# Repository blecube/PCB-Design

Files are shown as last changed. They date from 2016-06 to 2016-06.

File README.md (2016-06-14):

##BLE CUBE - PCB Design
This is the repository for all PCB Design files. Included in this repository is:

####BLE Card
This card features three 8-bit shift registers. The parallell outputs of these can be found alongside the edges of the card.
BLE Card supports two types of accelerometers. One internal [(LIS2DH12)](http://www.st.com/content/ccc/resource/technical/document/datasheet/12/c0/5c/36/b9/58/46/f2/DM00091513.pdf/files/DM00091513.pdf/jcr:content/translations/en.DM0009151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) that features its own traces and a header pin for an external accelerometer.

For more information, see pin assignements and pin map.

Also available is Components and Bill of Materials, BOM. Some of the used components are not included. See bottom of the BOM for details.
Further information on the circuits reference design can be found at Nordic Semiconductors infocenter

**Disclaimer!** This PCB as it is now is designed for use with LEDs that runs on 3V. Resistors are 390 ohm, but should be lower if 3v LEDs are to utilized. This part of the project was significantly modified in our case. This must be kept in mind if you want to replicate the project. In our case, the shiftregisters was modified to run on 4.2V in order to function with the LEDs.

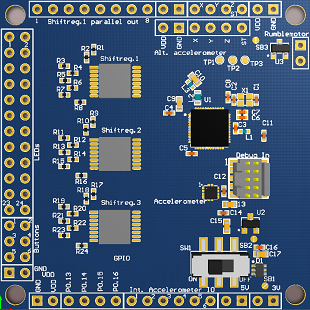
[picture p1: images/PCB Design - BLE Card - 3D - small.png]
BLE Card


####Adapter Card
* Designed for using [Adafruits chargecircuit](https://www.adafruit.com/product/259).
* Can be modified to send battery status lines to either P0.30 and P0.29, or P0.13 and P0.14. These can be used to program the cube to indicate "charging" or "charge complete".

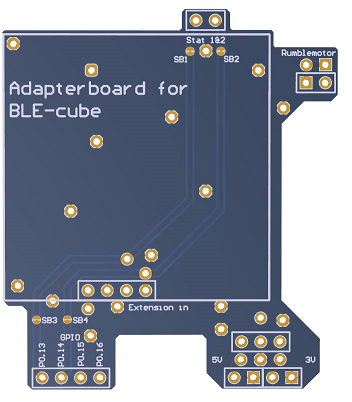
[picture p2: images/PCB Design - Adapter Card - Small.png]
BLE Card


####Schematic
The file called Schematics - BLE Card shows all connections, nets and components on the BLE Card.

####Recommended battery
If the adafruit charger is used, we recommend this battery to be used alongside our adapter card: [https://www.adafruit.com/products/328](https://www.adafruit.com/products/328)

> Created by Rasmus Espset

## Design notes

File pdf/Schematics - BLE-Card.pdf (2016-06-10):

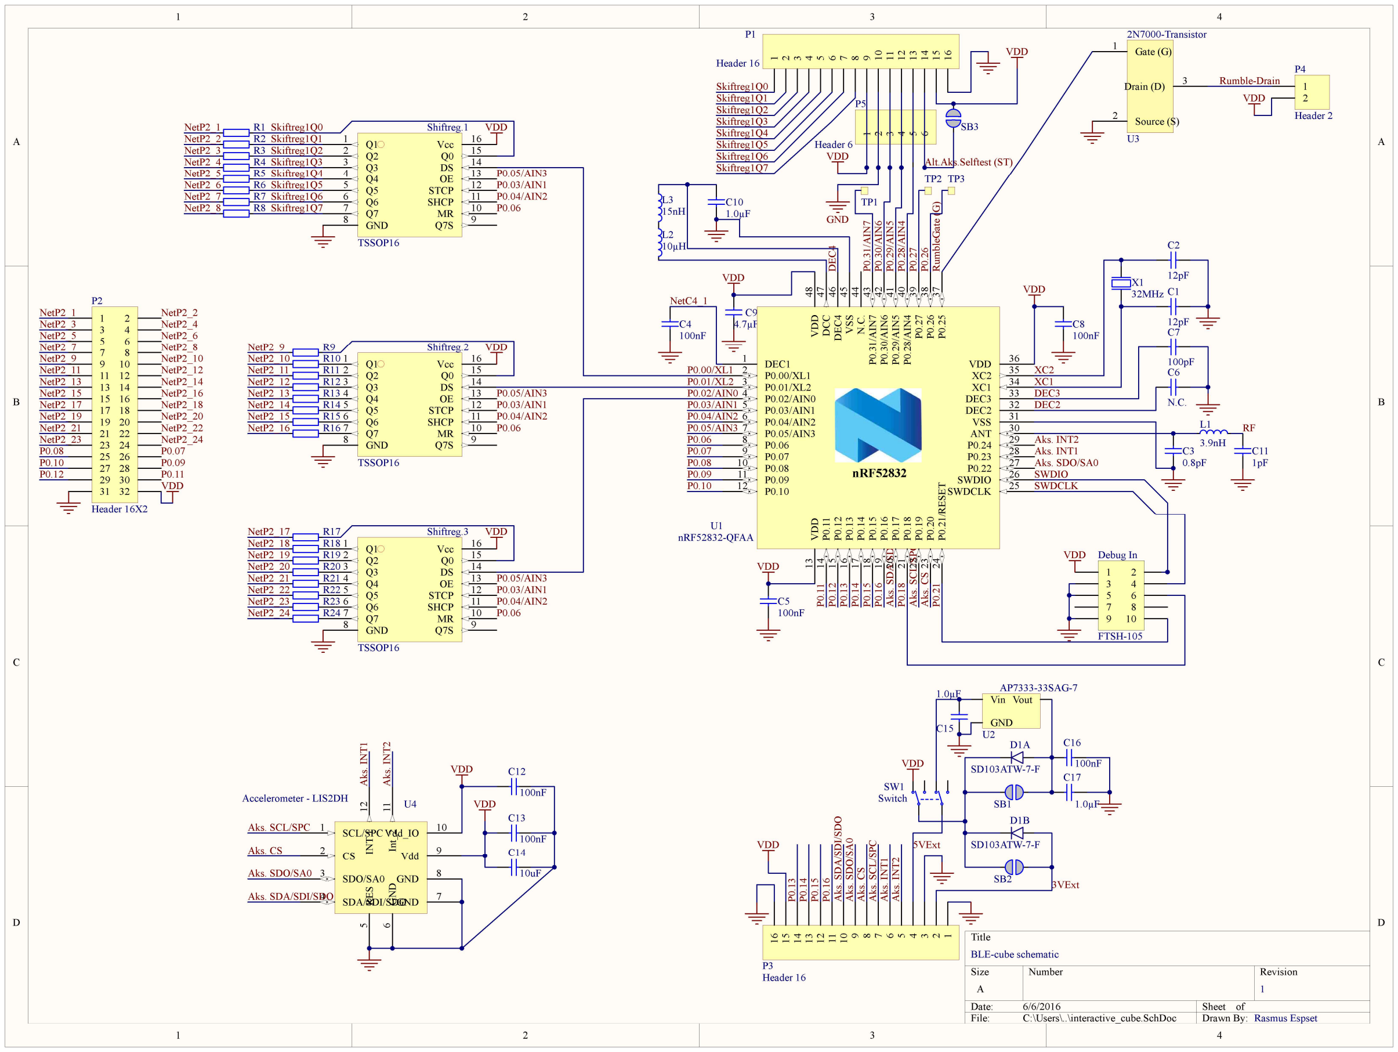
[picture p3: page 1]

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
Title
Size | Number | Revision
A
Date: | 6/6/2016 | Sheet of
File: | C:\Users\..\interactive_cube.SchDoc Drawn By:

X1
32MHz C1
12pF

C2
12pF

C7
100pF

C9
C4 4.7µF
100nF

C5
100nF

XC1

XC2

VDD

P0.07
P0.08
P0.10 | P⁰.11 P⁰.12 P⁰.13 P⁰.14 | Aks. SDA/SDI/SDO P⁰.18 Aks. SCL/SPC Aks. CS P⁰.21

Aks. SDO/SA0

Aks. INT1

Aks. INT2 RumbleGate ⁽G⁾
NetC4_1 | P⁰.29/AIN⁵ P⁰.28/AIN⁴

SWDCLK

SWDIO

L2
10µH

C10
1.0µF

L3
15nH

P0.06

RF
C3
0.8pF

C8
100nF

L1
3.9nH

C6
N.C.

P0.00/XL1

P0.01/XL2 | P⁰.27 P⁰.26

VDD

DEC1 1

P0.10 12 VDD 13

VSS 31
ANT 30

DEC2 32 DEC3 33 XC1 34 XC2 35 VDD 36 P⁰.25 37 P⁰.26 38

P0.00/XL1 2
P0.01/XL2 3
P0.02/AIN0 4
P0.03/AIN1 5
P0.04/AIN2 6
P0.05/AIN3 7
P0.06 8
P0.07 9
P0.08 10
P0.09 11 | P⁰.11 14 P⁰.12 15 P⁰.13 16 P⁰.14 17 | P⁰.27 39 P⁰.28/AIN⁴ ⁴⁰ P⁰.29/AIN⁵ ⁴¹ P⁰.30/AIN⁶ ⁴² P⁰.31/AIN⁷ ⁴³ N.C. 44 DEC⁴ ⁴⁶ VSS ⁴⁵ VDD ⁴⁸ DCC ⁴⁷

SWDCLK 25 SWDIO 26 P0.22 27 P0.23 28 P0.24 29 P⁰.15 18 P⁰.16 19 P⁰.17 20 P⁰.18 21 P⁰.20 23 P⁰.21/RESET 24 P⁰.19 22

### nRF52832

U1
nRF52832-QFAA

VDD

P0.02/AIN0 | DEC3
P0.03/AIN1
P0.04/AIN2
P0.05/AIN3 | P⁰.15 P⁰.16
P0.09 | DEC⁴ | P⁰.31/AIN⁷ P⁰.30/AIN⁶

DEC2

C11
1pF

1 2
3 4
5
7 8
9 10

6

Debug In

FTSH-105

Q2 2
Q3 3
Q4 4
Q5 5
Q6 6
Q7 7
GND 8 | Q7S 9 MR 10 SHCP 11 STCP 12 OE 13 DS 14 Q0 15 Vcc 16 Q1 1

Shiftreg.2

TSSOP16

Q2 2
Q3 3
Q4 4
Q5 5
Q6 6
Q7 7
GND 8 | Q7S 9 MR 10 SHCP 11 STCP 12 OE 13 DS 14 Q0 15 Vcc 16 Q1 1

Shiftreg.3

TSSOP16

SCL/SPC 1
CS 2
SDO/SA0 3
SDA/SDI/SDO 4 RES

### 5 GND

6

GND 7

GND 8

Vdd 9

Vdd_IO 10 Int_2 11 INT ¹ ¹² U4 Accelerometer - LIS2DH

C12
100nF
C13
100nF
C14
10uF

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
Switch

VDD

Source (S) 2

Drain (D) 3

Gate (G) 1

U3

2N7000-Transistor

VDD

VDD
SB3

D1A
SD103ATW-7-F

D1B
SD103ATW-7-F

SB1

SB2

C16
100nF

5VExt
3VExt

Vin
GND

Vout
U2

AP7333-33SAG-7

VDD

VDD 1

2

3

4

5

6

P5
Header 6

TP1

TP2 TP3

VDD

Aks. SCL/SPC
Aks. CS
Aks. SDO/SA0
Aks. SDA/SDI/SDO Aks. INT¹ Aks. INT² | P⁰.13 P⁰.14 P⁰.15 P⁰.16 Aks. SDA/SDI/SDO Aks. SDO/SA⁰ Aks. CS Aks. SCL/SPC Aks. INT¹ Aks. INT²

P0.12

P0.10

P0.08

NetP2_23

NetP2_21

P0.11

P0.09

P0.07

NetP2_24

NetP2_22

NetP2_20

NetP2_18

NetP2_16

NetP2_14

NetP2_12

NetP2_10

NetP2_8

NetP2_6

NetP2_4

NetP2_2

NetP2_19

NetP2_17

NetP2_15

NetP2_13

NetP2_11

NetP2_9

NetP2_7

NetP2_5

NetP2_3

NetP2_1

Skiftreg1Q0
Skiftreg1Q1
Skiftreg1Q2
Skiftreg1Q3
Skiftreg1Q4
Skiftreg1Q5
Skiftreg1Q6
Skiftreg1Q7

NetP2_24

Skiftreg1Q0
Skiftreg1Q1
Skiftreg1Q2
Skiftreg1Q3
Skiftreg1Q4
Skiftreg1Q5
Skiftreg1Q6
Skiftreg1Q7

NetP2_1
NetP2_2
NetP2_3
NetP2_4
NetP2_5
NetP2_6
NetP2_7
NetP2_8

P0.05/AIN3

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
116151413121110
P3
Header 16

Q2 2
Q3 3
Q4 4
Q5 5
Q6 6
Q7 7
GND 8 | Q7S 9 MR 10 SHCP 11 STCP 12 OE 13 DS 14 Q0 15 Vcc 16 Q1 1

Shiftreg.1

TSSOP16

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
910111213141516

P1
Header 16

1 2
3 4
5 6
7 8
9 10
11 12
13 14
15 16
17 18
19 20
21 22
23 24
25 26
27 28
29 30
31 32

P2

Header 16X2

P0.06

P0.06

P0.06

P0.05/AIN3

P0.05/AIN3

P0.04/AIN2

P0.04/AIN2

P0.04/AIN2

P0.03/AIN1

P0.03/AIN1

P0.03/AIN1

NetP2_9
NetP2_10
NetP2_11
NetP2_12
NetP2_13
NetP2_14
NetP2_15
NetP2_16

NetP2_17
NetP2_18
NetP2_19
NetP2_20
NetP2_21
NetP2_22
NetP2_23

Alt.Aks.Selftest (ST)

1
2

P4

Header 2

Rumble-Drain

C17
1.0µF

C15

1.0µF

BLE-cube schematic

Rasmus Espset

1

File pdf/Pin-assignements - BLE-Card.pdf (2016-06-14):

## 1.1 Pin-assignements - BLE-cube circuit board (nRF52)

http://bit.ly/1XA3fwh

Name | Pin | Type / Function | Comment
DEC1 | 1 | Decoupling cap. 1 | 0V9 regulator digital supply decoupling.
P0.00 | 2 | Serial data 1 | Shiftreg.1: serial data input.
P0.01 | 3 | Serial data 2 | Shiftreg.2: serial data input.
P0.02 | 4 | Serial data 3 | Shiftreg.3: serial data input.
P0.03 | 5 | RCLK | Shiftreg.1, 2, 3: storage register clock.
P0.04 | 6 | SRCLK | Shiftreg.1, 2, 3: shift register clock.
P0.05 | 7 | OE (inv.) | Shiftreg.1, 2, 3: Output Enable.
P0.06 | 8 | SRCLK (inv.) | Shiftreg.1, 2, 3: direct overriding clear.
P0.07 | 9 | Button 2 | GPIO, used for button inputs.
P0.08 | 10 | Button 1 | GPIO, used for button inputs.
P0.09 | 11 | Button 4 | GPIO, used for button inputs.
P0.10 | 12 | Button 3 | GPIO, used for button inputs.
VDD | 13 | Power | Supply Voltage.
P0.11 | 14 | Button 6 | GPIO, used for button inputs.
P0.12 | 15 | Button 5 | GPIO, used for button inputs.
P0.13 | 16 | P0.13 | GPIO.
P0.14 | 17 | P0.14 | GPIO.
P0.15 | 18 | P0.15 | GPIO.
P0.16 | 19 | P0.16 | GPIO.

P0.17 | 20 | Accel. SDA/SDI/SDO | Internal accelerometer pin (GPIO if unused).
P0.18 | 21 | Debug pin 6: TRACECTL | Single Wire Output.
P0.19 | 22 | Accel. SCL/SPC | Internal accelerometer (GPIO if unused).
P0.20 | 23 | Accel. CS | Internal accelerometer (GPIO if unused).
P0.21/RESET | 24 | Reset | Debug pin 10.
SWDCLK | 25 | Debug pin 4 | Serial Wire Debug clock input for debug and programming.
SWDIO | 26 | Debug pin 2 | Serial Wire Debug I/O for debug and programming.
P0.22 | 27 | Accel. SDO/SA0 | Internal accelerometer pin (GPIO if unused).
P0.23 | 28 | Accel. INT1 | Internal accelerometer pin: Interrupt signal 1 (GPIO if unused).
P0.24 | 29 | Accel. INT2 | Internal accelerometer pin: Interrupt signal 2 (GPIO if unused).
ANT | 30 | RF | Single-ended radio antenna connection.
VSS | 31 | Power | Ground pin (Radio supply).
DEC2 | 32 | Decoupling cap. 2 | 1V3 regulator supply decoupling (Radio supply).
DEC3 | 33 | Decoupling cap. 3 | Power supply decoupling.
XC1 | 34 | Analog Input | Connection for 32 MHz crystal.
XC2 | 35 | Analog Input | Connection for 32 MHz crystal.
VDD | 36 | Power | Supply Voltage.
P0.25 | 37 | RumbleGate (G) | Gate on transistor U3.
P0.26 | 38 | TP3 | Testpoint 3.
P0.27 | 39 | TP2 | Testpoint 2.
P0.28 | 40 | Z-signal - (AIN4 - Analog input) | External accelerometer: Z-values.
P0.29 | 41 | Y-signal - (AIN5 - Analog input) | External accelerometer: Y-values.

P0.30 | 42 | X-signal - (AIN6 - Analog input) | External accelerometer: X-values.
P0.31 | 43 | TP1 (AIN7 - Analog input) | Testpoint 1.
N.C | 44 | | Not Connected.
VSS | 45 | Power | Ground Pin.
DEC4 | 46 | Decoupling cap. 4 | 1V3 regulator supply decoupling. Input from DC/DC regulator. Output from 1.3 V LDO.
DCC | 47 | Power | DC/DC regulator output pin.
VDD | 48 | Power | Supply Voltage.

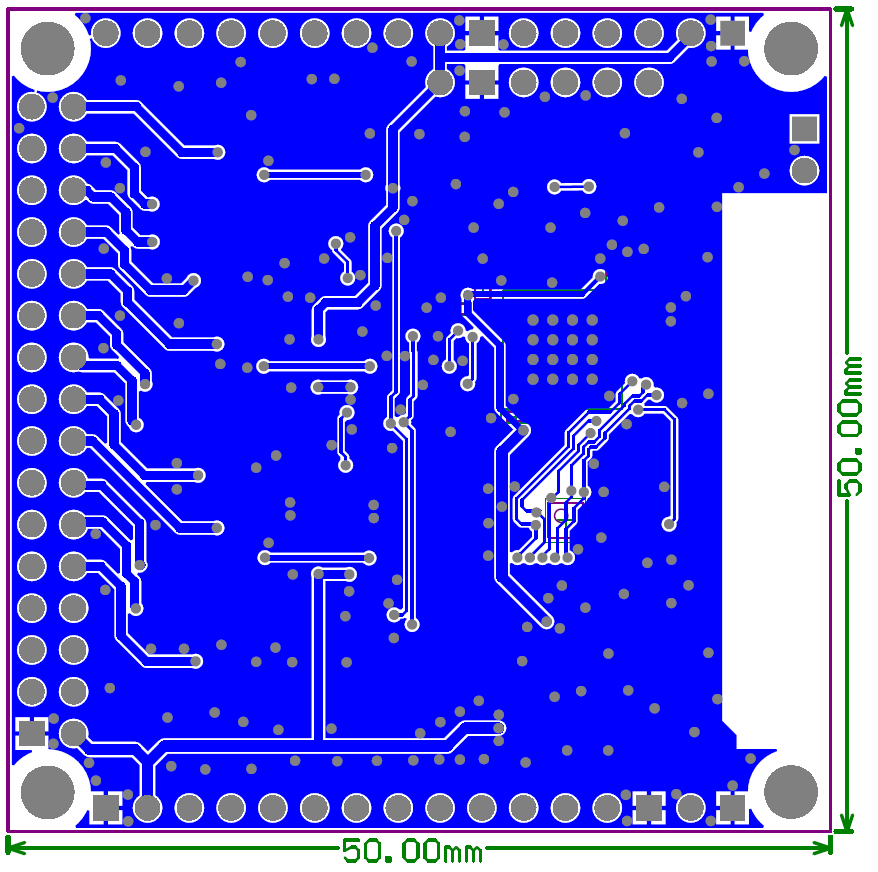
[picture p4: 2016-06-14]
images/PCB Design - BLE Card - Copper Bottom.png

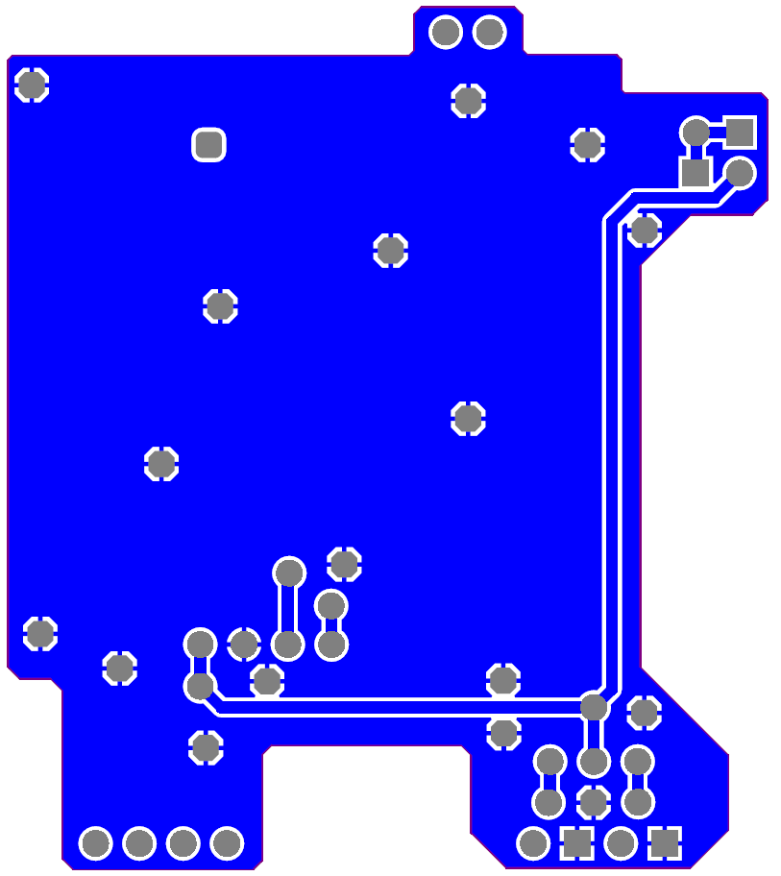
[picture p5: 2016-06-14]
images/PCB Design - Adapter Card - Copper Bottom.png

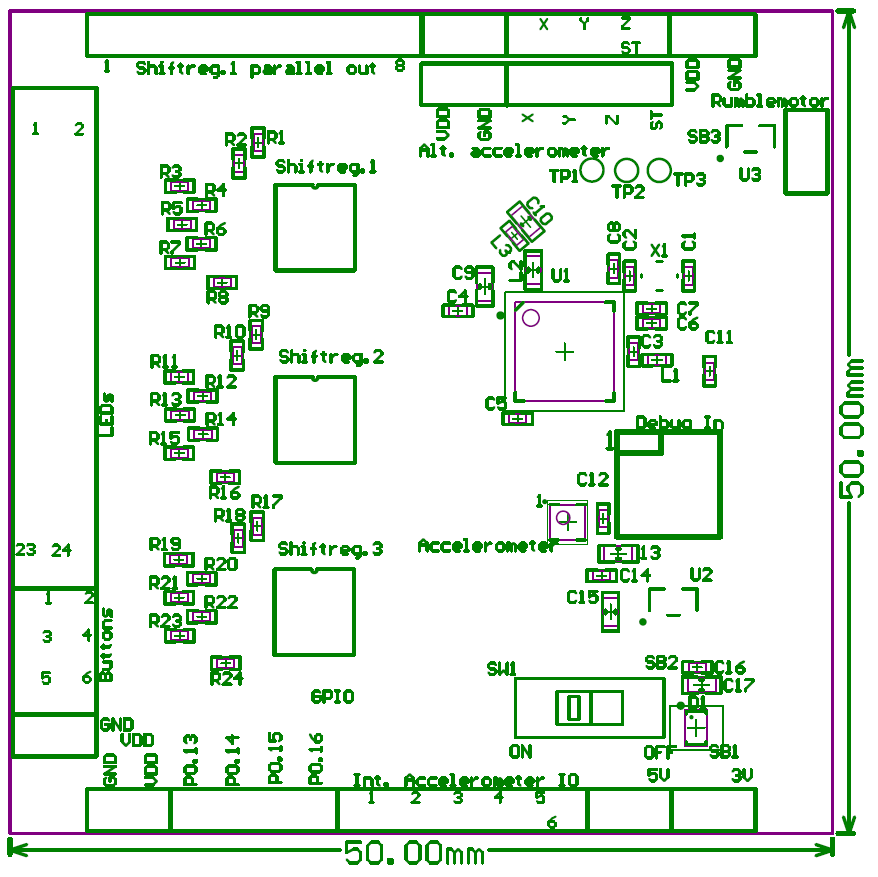
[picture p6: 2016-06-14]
images/PCB Design - BLE Card - Text.png

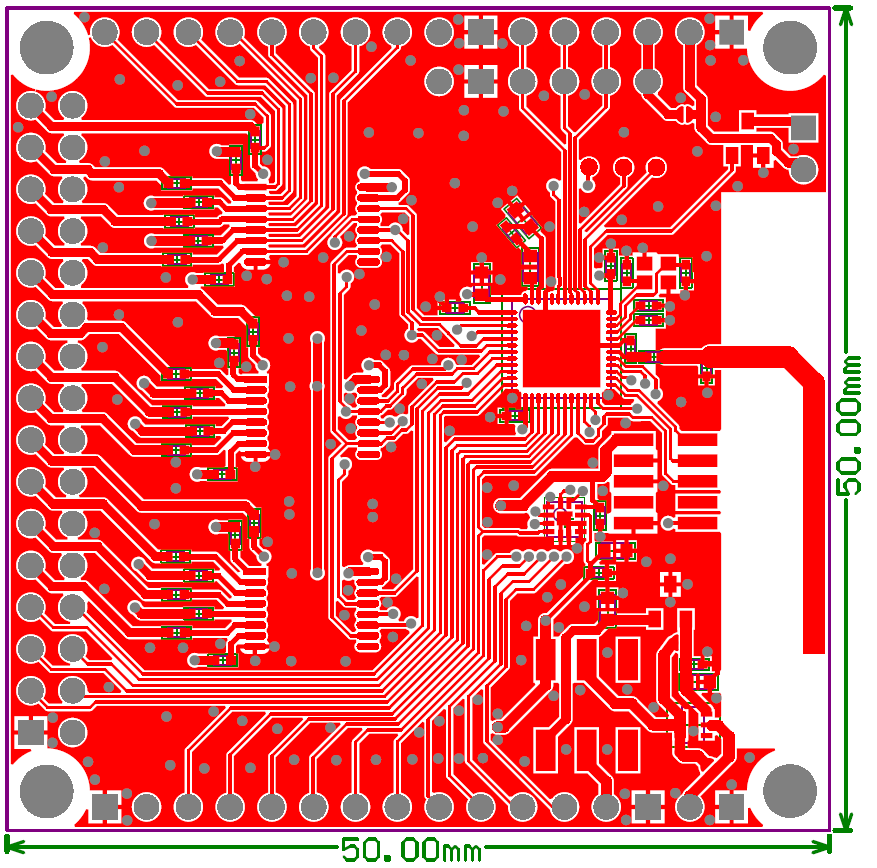
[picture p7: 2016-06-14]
images/PCB Design - BLE Card - Copper Top.png

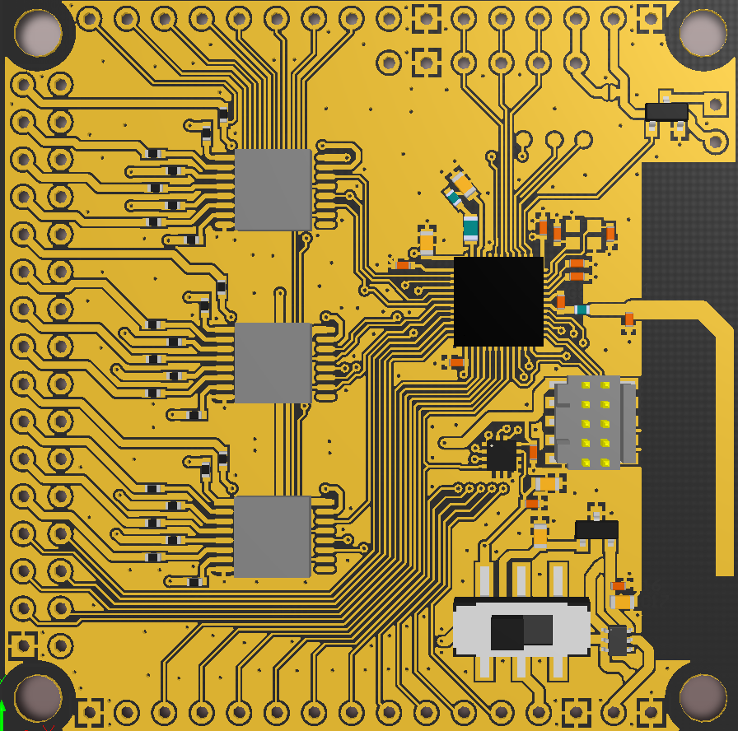
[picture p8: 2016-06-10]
images/PCB Design - BLE Card - 3D - Copper Top.png

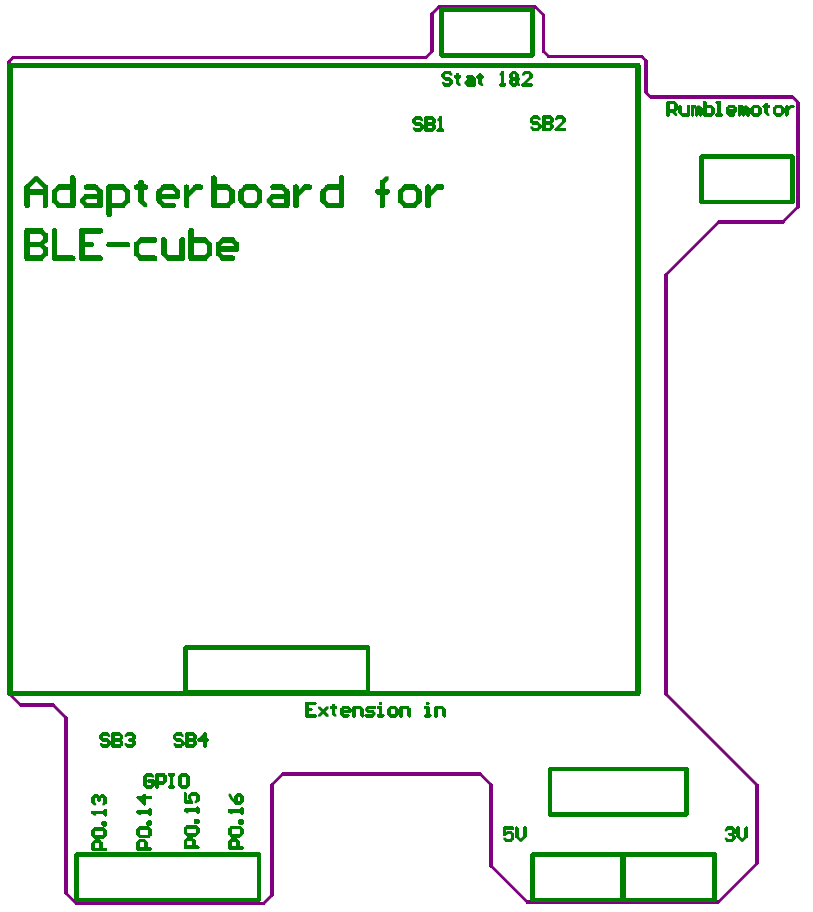
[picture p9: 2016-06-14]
images/PCB Design - Adapter Card - Text.png

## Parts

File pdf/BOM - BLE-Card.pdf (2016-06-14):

## 1.1 BOM – Bill Of Materials

Part name | Package | Qua-ntity | Description | Supplier | Supplier part number
NRF52832-QFAA | QFN40P600X600X90 -48N | 1 | Multi-protocol Bluetooth Low Energy and 2.4GHz proprietary system-on-chip | Nordic Semicon ductor
74HC595 | SOP16 | 3 | Shift register | Digi-Key | 568-2263-1-ND
SW-DPDT | JS202011SCQN | 1 | SMD slide Switch (ON-ON) | Digi-Key | 401-2002-1-ND
SD103ATW-7-F | SOT-363 | 1 | Surface Mount Schottky Barrier Diode Array | Digi-Key | SD103ATW-FDICT-ND
AP7333-33SAG-7 | SOT-23 | 1 | 300mA, Low Quiescent Current, Fast Transient Low Dropout Linear Regulator | Digi-Key | AP7333-33SAG-7DICT-ND
LIS2DH12 | LGA-12 | 1 | Ultra-low-power highperformance three-axis linear accelerometer | Digi-Key | 497-14851-1-ND
Samtec FTSH-105 Keying Shroud | FTSH-105-K | 1 | Debug In - Samtec - Conn Header 10pos dual .05" SMD Keying Shroud | Digi-Key | SAM8796-ND
2N7002 | SOT-23 | 1 | N-Channel Enhancement Mode Field Effect Transistor | Digi-Key | 2N7002LT1GOS CT-ND
RESC1005X04L | 0402 | 24 | Chip Resistor, 2-Leads, Body 1.0x0.5mm, IPC High Density | Digi-Key | P390LCT-ND
XTAL_SMD2016_3 2MHz_8pF_Epson | BT-XTAL_2016 | 1 | XTAL SMD 2016, 32MHz, Cl=8pF, Total Tol: ±40ppm | Farnell | 171-2806
Capacitor | CAPC1005X04L | 6 | 100nF - Capacitor, X7R, ±10% | Digi-Key | 1276-1001-1-ND
Capacitor | CAPC1005X04L | 2 | 12pF - Capacitor, NP0, ±2% | Digi-Key | 712-1256-1-ND
Capacitor | CAPC1005X04L | 1 | 100pF - Capacitor, NP0, ±5% | Digi-Key | 709-1123-1-ND
Capacitor | CAPC1005X04L | 1 | 1pF - Capacitor, NP0, ±0.1pF | Digi-Key | 490-6073-1-ND
Capacitor | CAPC1005X04L | 1 | 0,8pF - Capacitor, NP0, ±5% | Digi-Key | 490-11253-1-ND
Capacitor | CAPC1608X06L | 3 | 1uF - Capacitor, X7R, ±10% | Digi-Key | 1276-1946-1-ND

Capacitor | CAPC1608X06L | 1 | 10uF - Capacitor, NP0, ±2% | Digi-Key | 445-11185-1-ND
Capacitor -Nichicon UKL1C100KDD1TD | UKL1C100KDD1TD | 1 | Cap Alum 10uF 10% 16V Radial | Digi-Key | 493-14344-1-ND
Capacitor | CAPC1608X06L | 1 | 4,7uF - Capacitor, X5R, ±10% | Digi-Key | 1276-1045-1-ND
Inductor | INDC1608X06L | 1 | 10uH - Chip inductor, IDC,min = 50 mA, ±20% | Digi-Key | 587-1714-1-ND
Inductor | INDC1005X04L | 1 | 15nH - High frequency chip inductor ±10% | Digi-Key | 587-1521-1-ND
Inductor | INDC1005X04L | 1 | 3,9nH - High frequency chip inductor ±5% | Digi-Key | 490-1131-1-ND
RGB LED | | 6 | Lightdiode - Red, Green, Blue | RS | 835-2891
Switch | | 6 | SWITCH TACT SPST-NO 0.025A 50V | Digi-Key | EG1328-ND
Switch | | 1 | SLIDE SWITCH DPDT GULLWING 6V | Digi-Key | CAS220GCT-ND
Battery | | 1 | | | https://www.adafruit.com/products/328 (https://www.adafruit.com/products/328)
Charge circuit | | 1 | | | https://www.adafruit.com/product/2 59 (https://www.adafruit.com/product/259)

Note: Some components, such as the rumble engine, or the microUSB-input and headers has been scavenged from other sources and is thus not included in this BOM.
